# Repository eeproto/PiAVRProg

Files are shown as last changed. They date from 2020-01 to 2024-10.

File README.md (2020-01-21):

# Standalone AVR Programmer
Raspberry Pi based standalone ZIF Socket AVR Programmer

Program AVR chips with one click of a button:

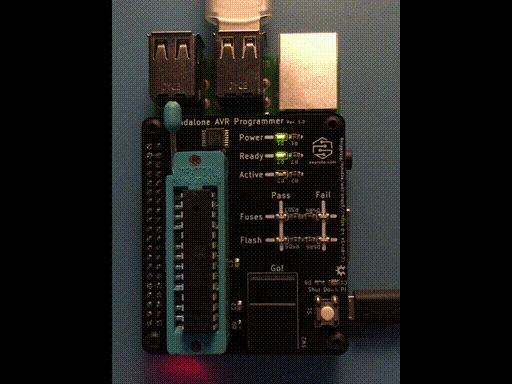
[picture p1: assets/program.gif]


Project Home Page: [https://eeproto.com/portfolio/avr-programmer/](https://eeproto.com/portfolio/avr-programmer/)

# Purpose

You designed a piece of hardware around an [AVR](https://en.wikipedia.org/wiki/AVR_microcontrollers) microcontroller, maybe the popular [ATmega328](https://www.microchip.com/wwwproducts/en/ATmega328). I love this powerful and inexpensive chip. Many projects use it, maybe because it is also the core of the even more popular [Arduino UNO](https://www.arduino.cc/en/Guide/ArduinoUno).

If you produce your new design two or three times, you flash your AVRs straight from your workstation. If you make 1,000, your distributor will gladly flash them for you. But what if you want, say, 50?

This project gives you all the parts to make a standalone, easy to use AVR programmer. It is Open Source, released under [Creative Commons Attribution-ShareAlike 4.0 International License](http://creativecommons.org/licenses/by-sa/4.0/), and it borrows from many other Open Source designs, including Sparkfun's [Pi AVR Programmer HAT](https://www.sparkfun.com/products/14747).

Hardware and software were tested with ATmega168 and ATmega328 chips. Feel free to adapt it to other AVR chips that support SPI programming.

# Make It

To make your own, get a Rasperry Pi. Any version should work, I tested it with a Pi 2 Model B v.1.1.

Make the custom PCB that connects the AVR socket, buttons, LEDs, etc. to the Pi.

Use the [KiCad](https://www.kicad-pcb.org/) project in the `hardware` folder to order your board. I got some from a low-cost PCB shop along with a stencil. It is a two-layer board with surface mount components on one side. There is a set of Gerber and drill files in the `hardware/plots` folder. The BOM in the same folder uses pretty generic components. The [octopart BOM](https://octopart.com/bom-tool/K1k6iRbx) might still be up.

Populate the surface mount components first. I use solder past, a stencil, tweezers, and a [ReflowR](http://www.reflowr.com/index.html) by [Lafras H](https://www.tindie.com/stores/LafrasH/). There are many other ways to do that, including hand soldering or reflowing with hot air like in this [EEVblog video](https://www.youtube.com/watch).

The 28 pin ZIF sockets can be a little hard to get, the major distributors might not have them in stock. Generic sockets through ama*** worked, too. Just make sure you get 28 pins in two rows with a 7.62mm / 0.3in row spacing.

If you don't feel comfortable with all of that, [email me](mailto:hello@eeproto.com), maybe I have some left over.

Add the through-hole parts. Double check you did not make any inadvertent solder bridges, then plug it in.

Support the PCB on top of your Pi with Nylon hex standoffs and secure everything with M3 screws.

Install the software by following the [Installation Guide](Installation.md).

# Prepare It

In order to program the AVR, you need two things:

1. A compiled HEX flash file.
2. The device configuration.

## 1. HEX file

Write and test your AVR firmware as usual. You can use [PlatformIO](https://platformio.org/), the [Arduino IDE](https://www.arduino.cc/en/Main/Software), a straight `avr-gcc` toolchain, or any other way. Build your project. 

Find the compiled HEX file. For Platform IO, look for a file `firmware.hex` in a folder `.pio/build/uno` underneath your project directory.

Copy this file to the root of a USB drive and name it `firmware.hex`. A standard FAT32 formatted drive works fine.

## 2. Device Configuration

Create a JSON file called `device.json` next to the HEX file on the USB drive. You can use the file from the `samples` folder as a starting point.

Adjust the AVR fuse settings to your needs. Here are a few samples:

| Fuses  | Settings |
|---|---|
| (E:FF, H:D9, L:E2) |Internal 8 MHz oscillator|
| (E:FF, H:D9, L:62) |Internal 1 MHz oscillator|
| (E:FD, H:DE, L:FF) | External 16 MHz crystal|
| (E:FD, H:DE, L:FF) | default Arduino UNO settings |

Set the chip type so avrdude knows what signature to expect. Common types:

|Type|Signature|
|---|---|
|atmega168|1e9406|
|atmega168p|1e940b|
|atmega168pb|1e9415|
|atmega328|1e9514|
|atmega328p|1e950f|
|atmega328pb|1e9516|

Check this [post](https://www.avrfreaks.net/forum/device-signatures) for a full list.

Example configuration file:
```json device.json
{
  "E": "FF",
  "H": "D9",
  "L": "E2",
  "type": "atmega328p"
}
```

# Use It

1. [Assemble](#make-it) the hardware and [install](Installation.md) the Pi firmware.
1. [Prepare](#prepare-it) the USB flash drive with your hex file and device configuration.
1. Power the Pi.
1. You should see the `Power` LED turn on.
1. The `Ready` LED is flashing until a USB drive with a valid device configuration and hex file is plugged in. Plug it in and wait for the `Ready` LED to turn solid green.
1. Insert an AVR chip that matches your device configuration into the ZIF socket and lock the socket. The index notch is at the top next to the title print.
1. Press the `Go!` button.
1. The `Active` LED turns on.
1. If the device needs updated fuse settings, the `Fuses Pass` LED should go green after a moment.
1. The `Flash Pass` LED goes green once flashing was successful.
1. If at any time a `Fail` LED starts flashing, the programmer was unsuccessful communicating with the AVR chip. Check everything is wired correctly and the AVR is secure in its place with Pin 1 at the top. Try a different AVR chip. If this problem continues to exist, try reducing the programming bitclock in the Python script. 

# How It Works

The Pi runs a small Linux OS based on PipaOS. On boot, it starts a Python script as a background system service.

This script reads the USB drive, looking for both a flash HEX file and a device configuration JSON file. 

If both are there, the script starts monitoring the big pushbutton labeled `Go!`.

When you press the button, the script runs avrdude to first check the device signature. Then, it reads the fuses. If they need to be programmed, it does that. Last, it writes the HEX file contents to the AVR flash memory.

Looking at the output of the avrdude commands, the script lights the LEDs to tell you what worked and what did not.

You can pull power from the Pi without shutting it down, because PipaOS allows the SD card to be mounted read-only.

The custom PCB mainly connects the SPI lines provided by the Pi to the AVR. A 4066 isolates the two chips when not programming, as the AVR might go into SPI master mode after releasing the RESET line. One momentary push button with a little ESD protection starts the programming, another one allows a clean shutdown of the Pi, in case you decide to run with a different OS setup.

To connect the AVR, you can use any standard socket, although a ZIF socket allows for frustration free insert and removal.

Although it looks like a HAT, technically this is not a HAT according to the [HAT Design Guide](https://github.com/raspberrypi/hats/blob/master/designguide.md). It still fits nicely on top of the Pi.

# Known Issues

For reasons I don't know, my prototype assemblies would only flash at a bitrate of around 200 kHz. A dirty breadboard assembly ran up to 2MHz. Need to figure out why that is.

# Credits

This project depends heavily on other people's great open source work, including:

- The [PipaOS](http://pipaos.mitako.eu/) Linux distribution by Albert Casals
- [avrdude](http://savannah.nongnu.org/projects/avrdude/) AVR programmer
- Kevin's [linuxspi](http://kevincuzner.com/2013/05/27/raspberry-pi-as-an-avr-programmer/) extension for avrdude
- Steve's [programmer design](https://blog.stevemarple.co.uk/2012/07/avrarduino-isp-programmer-using.html) with 74LVC244 isolating buffers
- adafruit's [linuxgpio-based design](https://learn.adafruit.com/program-an-avr-or-arduino-using-raspberry-pi-gpio-pins?view=all)
- Mark Williams shows how to operate the Pi [with the Arduino IDE](http://ozzmaker.com/program-avr-using-raspberry-pi-gpio/)
- QCPete's [writeup](https://learn.sparkfun.com/tutorials/raspberry-pi-stand-alone-programmer/all) on the design of the [Pi AVR Programmer HAT](https://www.sparkfun.com/products/14747)
- Volker Urban's [Pi/AVR summary](https://www.mikrocontroller.net/articles/Raspberry_Pi_als_Universalprogrammer) (german)
- [KiCad](https://www.kicad-pcb.org/), an exceptional and Open Source electronics design software
- Chris Gammell's [Contextual Electronics Forum](https://forum.contextualelectronics.com/) as an endless source of great knowledge.

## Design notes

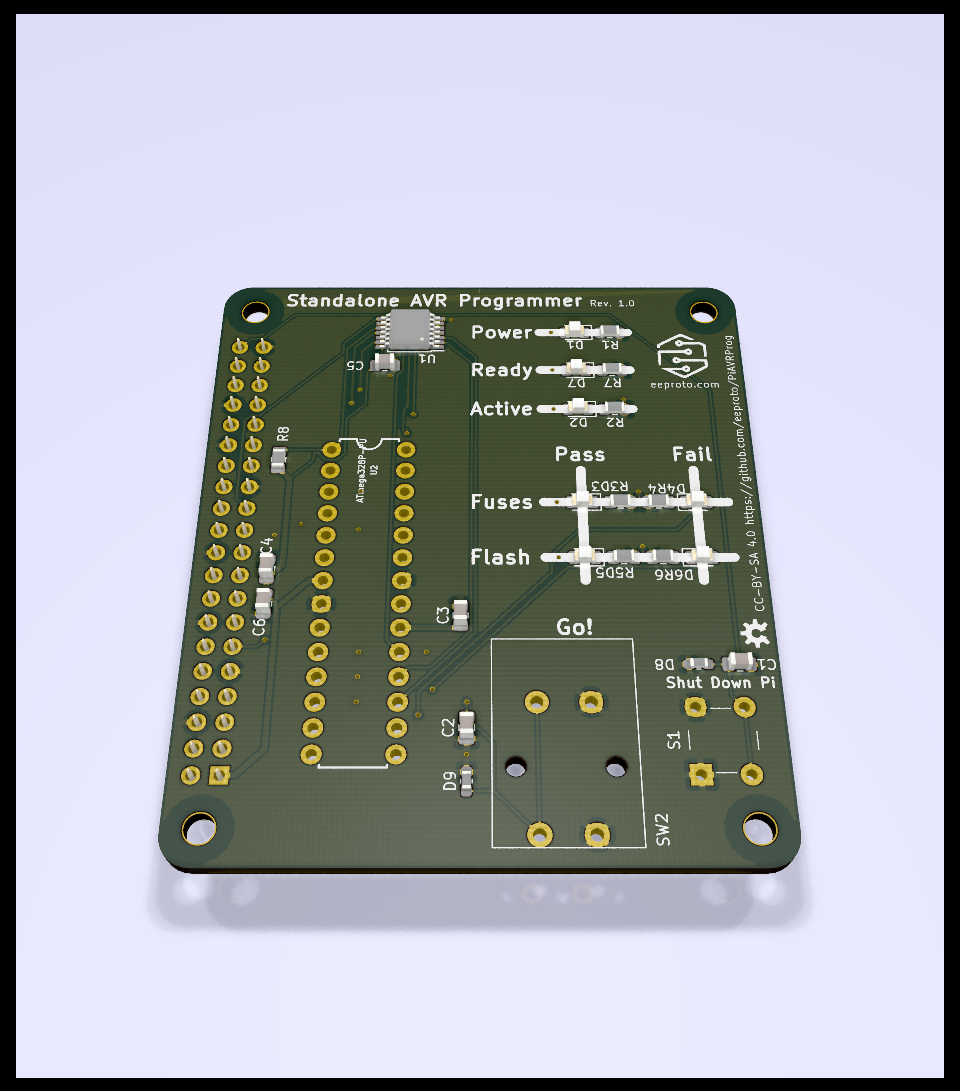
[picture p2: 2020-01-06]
hardware/PiAVRProg/plots/rendering.png

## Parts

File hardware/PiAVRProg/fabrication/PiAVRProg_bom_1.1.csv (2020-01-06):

Component | Description | Part | References | Value | Footprint | Quantity Per PCB | Datasheet | MPN | MFR | Comment | Category | Status | Family | Digi-Key_PN | DK_Datasheet_Link | DK_Detail_Page | Manufacturer
1 | Unpolarized capacitor | C | C1 C2 C3 C4 C5 | 0.1uF | C_0805_2012Metric_Pad1.15x1.40mm_HandSolder | 5 | ~ | 885012207128 | Wurth Elektronik
2 | Unpolarized capacitor | C | C6 | 10uF | C_0805_2012Metric_Pad1.15x1.40mm_HandSolder | 1 | ~ | 885012107014 | Wurth Elektronik
3 | Bidirectional transient-voltage-suppression diode | D_TVS | D8 D9 | D_TVS | R_0603_1608Metric_Pad1.05x0.95mm_HandSolder | 2 | ~ | CG0603MLE-18E | Bourns Inc.
4 | Light emitting diode | LED | D1 D3 D5 D7 | GREEN | LED_0805_2012Metric_Pad1.15x1.40mm_HandSolder | 4 | ~ | LTST-S220GKT LTST-S220EKT | Lite-On | Power Fuse Pass Flash Pass Ready
5 | Light emitting diode | LED | D4 D6 | RED | LED_0805_2012Metric_Pad1.15x1.40mm_HandSolder | 2 | ~ | LTST-S220EKT | Lite-On | Fuse Fail Flash Fail
6 | Light emitting diode | LED | D2 | YELLOW | LED_0805_2012Metric_Pad1.15x1.40mm_HandSolder | 1 | ~ | LTST-S220KSKT | Lite-On | Programming
7 |  | OX40HAT-raspberrypi_hat | J1 | 40HAT | PinSocket_2x20_P2.54mm_Vertical | 1 |  | SSW-120-01-T-D | Samtec Inc.
8 | Resistor | R | R1 R2 R3 R4 R5 R6 R7 | 100 | R_0805_2012Metric_Pad1.15x1.40mm_HandSolder | 7 | ~ | RC0805FR-07100RL | Yageo
9 | Resistor | R | R8 | 10k | R_0805_2012Metric_Pad1.15x1.40mm_HandSolder | 1 | ~ | RC0805FR-0710KL | Yageo
10 | SWITCH TACTILE SPST-NO 0.05A 24V | B3F-1000 | S1 | B3F-1000 | Switch_Tactile_THT_B3F-1xxx | 1 | https://omronfs.omron.com/en_US/ecb/products/pdf/en-b3f.pdf | B3F-1000 | Omron Electronics Inc-EMC Div | Shut Down | Switches | Active | Tactile Switches | SW400-ND | https://omronfs.omron.com/en_US/ecb/products/pdf/en-b3f.pdf | /product-detail/en/omron-electronics-inc-emc-div/B3F-1000/SW400-ND/33150 | Omron Electronics Inc-EMC Div
11 | Single Pole Single Throw (SPST) switch | SW_SPST | SW2 | MOM | OmronB3J1100 | 1 | ~ | B3J-1100 | Omron Electronics Inc-EMC Div | Go!
12 | Quad Analog Switches | 4066 | U1 | 4066 | TSSOP-14_4.4x5mm_P0.65mm | 1 | http://www.ti.com/lit/ds/symlink/cd4066b.pdf | 74LVC4066PW,118 | Nexperia USA Inc.
13 | 20MHz, 32kB Flash, 2kB SRAM, 1kB EEPROM, DIP-28 | ATmega328P-PU | U2 | ATmega328P-PU | DIL28-3-ZIF_SOCKET | 1 | http://ww1.microchip.com/downloads/en/DeviceDoc/ATmega328_P%20AVR%20MCU%20with%20picoPower%20Technology%20Data%20Sheet%2040001984A.pdf | 28-3551-10 | Aries Electronics
Component Groups: | 13
Component Count: | 28
Fitted Components: | 28
Number of PCBs: | 1
Total components: | 28
Schematic Version: | 1.1
Schematic Date: | 2020-01-02
PCB Variant: | [u'default']
BoM Date: | Mon 06 Jan 2020 12:44:06 PM EST
Schematic Source: | /home/christian/archiv/clients/open source/piavr/PiAVRProg/hardware/PiAVRProg/PiAVRProg.sch
KiCad Version: | Eeschema 5.0.2-bee76a0~70~ubuntu18.04.1

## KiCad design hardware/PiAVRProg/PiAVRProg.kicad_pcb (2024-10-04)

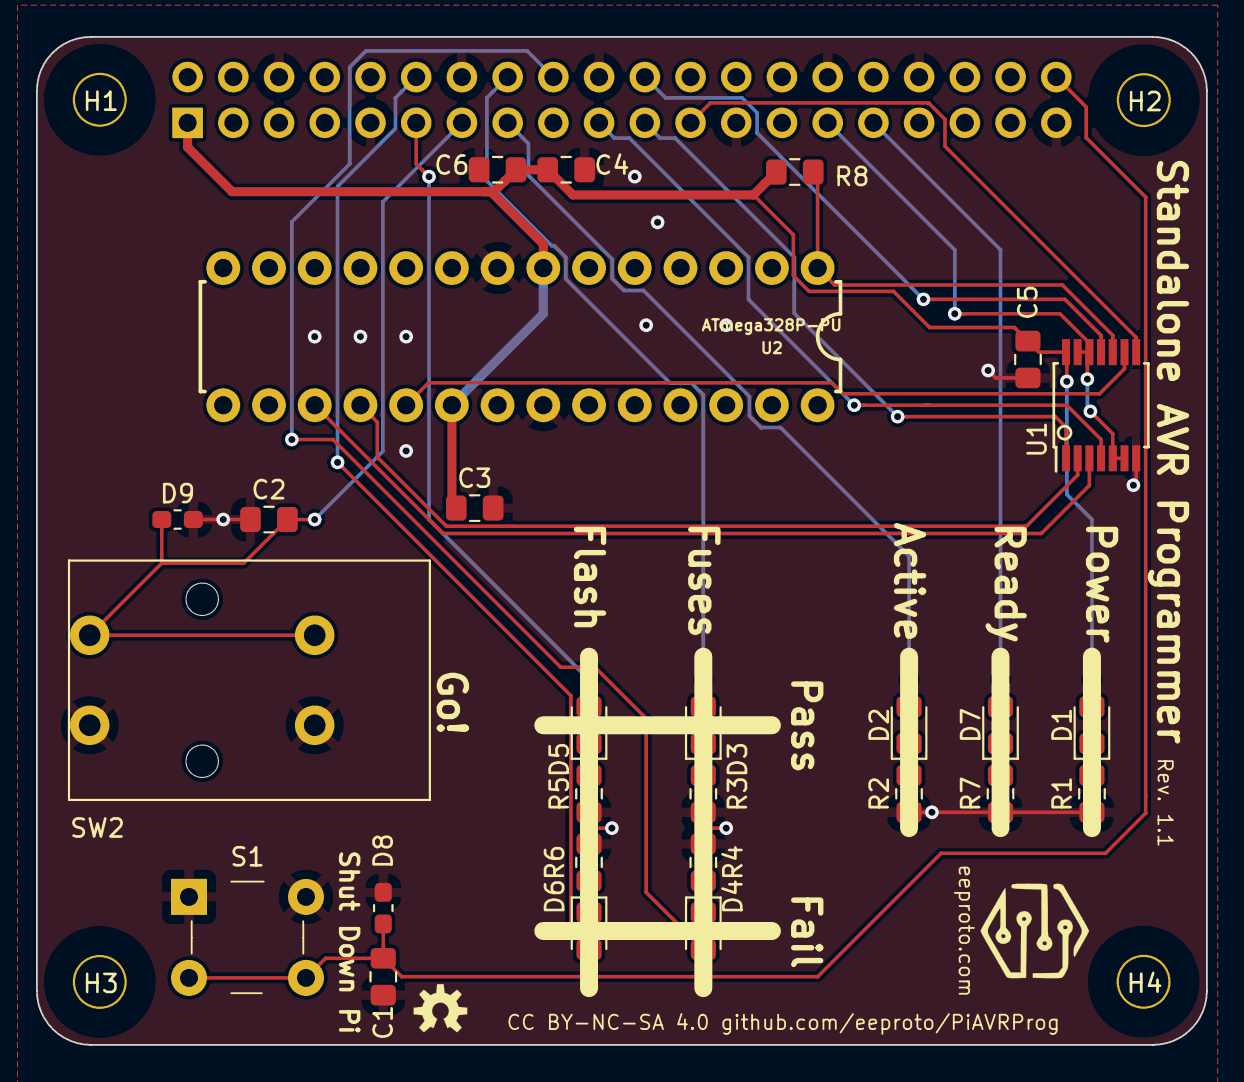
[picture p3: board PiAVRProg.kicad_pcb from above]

Board: 2 copper layers, 65.0 x 56.0 mm, 32 parts (1 on the bottom side), 26 nets.

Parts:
C1, C2, C3, C4, C5: 0.1uF; C_0805_2012Metric_Pad1.15x1.40mm_HandSolder
C6: 10uF; C_0805_2012Metric_Pad1.15x1.40mm_HandSolder
D1, D3, D5, D7: GREEN; LED_0805_2012Metric_Pad1.15x1.40mm_HandSolder
D2: YELLOW; LED_0805_2012Metric_Pad1.15x1.40mm_HandSolder
D4, D6: RED; LED_0805_2012Metric_Pad1.15x1.40mm_HandSolder
D8, D9: D_TVS; R_0603_1608Metric_Pad1.05x0.95mm_HandSolder
H1, H2, H3, H4: 3mm_Mounting_Hole; NPTH_3mm_ID
J1: 40HAT; PinSocket_2x20_P2.54mm_Vertical
R1, R2, R3, R4, R5, R6, R7: 1k; R_0805_2012Metric_Pad1.15x1.40mm_HandSolder
R8: 10k; R_0805_2012Metric_Pad1.15x1.40mm_HandSolder
S1: B3F-1000; Switch_Tactile_THT_B3F-1xxx
SW2: MOM; OmronB3J1100
U1: 4066; TSSOP-14_4.4x5mm_P0.65mm
U2: ATmega328P-PU; DIL28-3-ZIF_SOCKET

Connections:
+3V3: C3.1, C4.1, C5.1, C6.1, D1.2, J1.1, R8.1, U1.14, U2.7, U2.20
/AVR_CLK: U1.9, U2.19
/AVR_MISO: U1.2, U2.18
/AVR_MOSI: U1.3, U2.17
/AVR_RESET: R8.2, U1.10, U2.1
/FLASH_FAIL: D6.2, J1.12
/FLASH_PASS: D5.2, J1.11
/FUSE_FAIL: D4.2, J1.18
/FUSE_PASS: D3.2, J1.16
/PI_CLK: J1.23, U1.8
/PI_GO: C2.2, D9.1, J1.13, SW2.1
/PI_MISO: J1.21, U1.1
/PI_MOSI: J1.19, U1.4
/PI_RESET: J1.22, U1.11
/PI_SHUTDOWN: C1.2, D8.1, J1.40, S1.3, S1.4
/PROGRAMMING: D2.2, J1.15
/READY: D7.2, J1.31
/SPI_SWITCH: J1.29, U1.5, U1.6, U1.12, U1.13
GND: C1.1, C2.1, C3.2, C4.2, C5.2, C6.2, D8.2, D9.2, J1.6, J1.9, J1.14, J1.20, J1.25, J1.30, J1.34, J1.39, R1.1, R2.1, R3.1, R4.1, R5.1, R6.1, R7.1, S1.1, S1.2, SW2.2, U1.7, U2.8, U2.22
unnamed: D1.1, R1.2
unnamed: D2.1, R2.2
unnamed: D3.1, R3.2
unnamed: D4.1, R4.2
unnamed: D5.1, R5.2
unnamed: D6.1, R6.2
unnamed: D7.1, R7.2

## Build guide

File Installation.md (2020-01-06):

# Software Installation

The Software for this Programmer is built on top a Linux distribution. I chose [PipaOS](http://pipaos.mitako.eu/) by Albert Casals because it is fast, slim, can be installed as a read-only SD-card image, and it is generally great work. The read-only image helps extending the life of SD cards a lot.

If you want a ready-to-go image instead of going through the installation, [let me know](mailto:hello@eeproto.com) as I plan to upload one.

## 1. Install The OS

Grab a fresh SD card, min. 2 GB, and download your choice of PipaOS image. I used [pipaos-stretch-6.0.img.gz](http://pipaos.mitako.eu/download/pipaos-stretch-6.0.img.gz). Use an SD-card adapter to write the image. There are plenty of tools out there, like the [balena Etcher](https://www.balena.io/etcher/). Or use `dd`. Or `dc3dd`, which works like `dd` but is a little more talkative. Writing through the `/dev/disk/by-id/` nodes instead of `/dev/sdx` helps you to flash the SD card and not accidentally your hard disk.

```bash
wget http://pipaos.mitako.eu/download/pipaos-stretch-6.0.img.gz
sudo umount /dev/disk/by-id/usb-SanDisk_SDDR-B531_012345-0*
zcat ~/Downloads/pipaos-stretch-6.0.img.gz | sudo dc3dd verb=on of=/dev/disk/by-id/usb-SanDisk_SDDR-B531_012345-0\:0
```

## 2. Configure The OS

Get access to your freshly installed OS. 

Plug the SD card into your Pi, hook it up to your Ethernet, boot it up, and SSH into it. The default credentials are user `sysop` and password `posys`. Your router might be smart enough to pick up the default hostname `pipaos`. If not, use `nmap` to find a MAC address that looks like a Pi:

```bash
# with hostname resolution
ssh sysop@pipaos

# without
sudo nmap -sP 192.168.1.1-254
# look for something like this:
#   Nmap scan report for 192.168.1.29
#   Host is up (-0.099s latency).
#   MAC Address: B8:27:xx:xx:xx:xx (Raspberry Pi Foundation)
ssh sysop@192.168.1.29
```
Make your basic OS settings, something like this:
```bash
# always change the password first
passwd

# update and install a few useful tools including avrdude
sudo apt update
sudo apt install -y vim python3-virtualenv virtualenv screen git avrdude ntpdate
sudo apt upgrade

# choose and set your hostname
export HOSTNAME=piavr
sudo sed -i -e "s/pipaos/$HOSTNAME/" /etc/hosts
sudo sed -i -e "s/pipaos/$HOSTNAME/" /etc/hostname

# set your timezone and set the clock
sudo dpkg-reconfigure tzdata
sudo service ntp stop
sudo ntpdate pool.ntp.org

# disable a few services for faster startup
#  you can skip this if you don't know what these are
sudo systemctl disable avahi-daemon
sudo systemctl disable triggerhappy
sudo systemctl disable ntp
sudo systemctl disable wpa_supplicant
sudo systemctl disable apt-daily
sudo systemctl disable apt-daily-upgrade
sudo systemctl disable pipaos-bootlogo
sudo apt remove alsa-utils
```

Make sure [SPI is enabled](https://www.raspberrypi.org/documentation/hardware/raspberrypi/spi/README.md) by checking:

```bash
lsmod | grep spi
grep spi /boot/config.txt
```
 
`lsmod` should should report a module `spidev` loaded.

This line has to be in `/boot/config.txt` without a comment `#` sign in front:

```ini
dtparam=spi=on
```

## 3. Auto Mount USB Drive 

The AVR Hex file and device configuration will be supplied on a removable USB drive. We want to plug it into the Pi at any time without worrying about mounting it manually.

This modifies your `/etc/fstab` do to just that:

```bash
sudo mkdir /media/usb
sudo chattr +i /media/usb
echo "/dev/sda1  /media/usb  vfat  defaults,sync,nofail,noexec,nosuid,noatime,nodev,user  0 0" | sudo tee -a /etc/fstab
```

## 4. avrdude

We will use [avrdude](http://savannah.nongnu.org/projects/avrdude/) to actually program the AVR. Make sure we got the right version from the repo. You want at version 6.1 or newer with linux SPI support:

```bash
avrdude
# check to see "version 6.1" or newer

avrdude -c ?type 2> >(grep linux)
# look for a line starting with "linuxspi"
```

## 5. Python Scripts

For programming standalone, the Pi will run a background service that works with the buttons, LEDs, and avrdude. Install it from github and enable it:

```bash
# choose where you would like to install this
cd /var/lib/
sudo mkdir piavr
sudo chown sysop piavr
cd piavr

# wrap it into a virtual environment
virtualenv --python=/usr/bin/python3 .
source /var/lib/piavr/bin/activate
git clone https://github.com/eeproto/PiAVRProg
pip install -r PiAVRProg/software/scripts/requirements.txt

# install as a system service on boot
sudo ln -snf /var/lib/piavr/PiAVRProg/software/etc_systemd_system/avrprogrammer.service \
 /etc/systemd/system
sudo systemctl enable avrprogrammer.service
```

## Finish

Finally, make the root filesystem read-only:

```bash
sudo pipaos-lockfs lock persistent
```

If you need to make changes in the future, boot, log in, and temporarily remount as read-write:
```bash
sudo pipaos-lockfs unlock
# do stuff ..
sudo pipaos-lockfs lock
sudo reboot
```
PipaOS is great, right?

You could also do all that by mounting the SD card on your computer like this and do some clever chrooting:

```bash
sudo mount /dev/disk/by-id/usb-SanDisk_SDDR-B531_012345-0\:0-part1 /media/boot
sudo mount /dev/disk/by-id/usb-SanDisk_SDDR-B531_012345-0\:0-part2 /media/root
# ...
```

## Troubleshoot

Here are a few things you can try in case things don't work as expected. Log in to the Pi and do this on the commandline.

Plug in a fresh AVR chip and see if avrdude can find it: 
```bash
sudo avrdude -c linuxspi -v -p atmega328p -P /dev/spidev0.0
```

Try reading a few things from the chip:
```bash
# read signature at a low baud rate
sudo avrdude -c linuxspi -v -p atmega328p -b19200 -B10 -P /dev/spidev0.0
 
# read flash to binary file at 2MHz SPI clock
sudo avrdude -c linuxspi -v -p atmega328p -P /dev/spidev0.0 -v \
 -b 2000000 \
 -U flash:r:/tmp/flash.bin:r
```

Try manually writing:
```bash
# write fuses, -D no auto erase, 19200 SPI clock rate
sudo avrdude -c linuxspi -v -p atmega328p -P /dev/spidev0.0 -v \
 -b 19200 -B10 \
 -U efuse:w:0xFF:m -U hfuse:w:0xD9:m -U lfuse:w:0xE2:m
 
# write flash, no auto erase, -e chip erase, 2 MHz SPI clock
sudo avrdude -c linuxspi -v -p atmega328p -P /dev/spidev0.0 -v \
 -b 2000000 \
 -U flash:w:/tmp/firmware.hex:i
```

Try different bit clock rates and baud rates. Check the [online docs](https://www.nongnu.org/avrdude/user-manual/avrdude.html) for details. Modify the Python scripts accordingly.

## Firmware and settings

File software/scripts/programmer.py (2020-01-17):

#!/usr/bin/env python
# -*- coding: utf-8 -*-

"""
This file is part of the PiAVRProg project
 https://github.com/eeproto/PiAVRProg

This work is licensed under a Creative Commons Attribution-ShareAlike 4.0
 International License http://creativecommons.org/licenses/by-sa/4.0/

Copyright (c) 2019 EE Proto LLC https://www.eeproto.com

Author: christian@eeproto.com
"""

import RPi.GPIO as GPIO
import time
import json
import os
import logging
import traceback
import signal
import sys

import led
import button
import avrdude

DEVICE_FILE_PATH = '/media/usb/device.json'
FLASH_FILE_PATH = '/media/usb/firmware.hex'
DEVICE_KEYS = ['H', 'L', 'E', 'type']
SPI_DEVICE = '/dev/spidev0.0'
PROGRAMMER = 'linuxspi'
BAUDRATE_SLOW = '19200'
BITRATE_SLOW = '10'
BAUDRATE_FAST = '200000'
BITCLOCK_FAST = '1'
LOG_LEVEL = logging.INFO
VERSION = '0.2'


class PiProgrammer(object):

    def __init__(self):
        self.init_gpio()
        self.leds = {}
        self.led_ready = led.LED(6)
        self.leds['programming'] = led.LED(22)
        self.leds['flash_pass'] = led.LED(17)
        self.leds['flash_fail'] = led.LED(18)
        self.leds['fuse_pass'] = led.LED(23)
        self.leds['fuse_fail'] = led.LED(24)
        self.buffer_switch = led.LED(5)
        self.go_button = button.Button(27, self.button_pressed)
        self.clear_leds()
        self._alive = True

    def init_gpio(self):
        GPIO.setwarnings(False)
        GPIO.setmode(GPIO.BCM)

    def led_cycle(self, *args):
        l = list(self.leds.keys())
        l.sort()
        self.leds[l[self.x]].off()
        self.x = (self.x + 1) % len(self.leds)
        self.leds[l[self.x]].on()

    def clear_leds(self):
        for l in self.leds.values():
            l.off()
        self.led_ready.off()

    def load_firmware(self):
        device = {}
        try:
            logging.debug('reading device configuration from %s', DEVICE_FILE_PATH)
            with open(DEVICE_FILE_PATH, 'r') as f:
                device = json.load(f)
            device_ok = (len(set(device.keys()) & set(DEVICE_KEYS)) == len(DEVICE_KEYS))
            logging.debug('found %s keys in device file %s', len(DEVICE_KEYS), DEVICE_FILE_PATH)
        except Exception as ex:
            device_ok = False
            logging.error('error loading device file: %s', ex)
        try:
            logging.debug('opening flash file %s', FLASH_FILE_PATH)
            flash_size = os.path.getsize(FLASH_FILE_PATH)
            logging.debug('found %s byte flash file %s', flash_size, FLASH_FILE_PATH)
            flash_ok = (flash_size > 0)
        except Exception as ex:
            flash_ok = False
            logging.error('error loading flash file: %s', ex)
        return device, device_ok, flash_ok

    def button_pressed(self, *args):
        self.clear_leds()
        if self._ready_to_go:
            try:
                logging.info('begin programming')
                self.leds['programming'].on()
                self.buffer_switch.on()
                self.run_programming()
            except avrdude.AvrDeviceNotRespondingError as ex:
                logging.error('device not ready %s %s', type(ex), ex.args)
                logging.debug(traceback.format_exc())
                self.leds['fuse_fail'].blink(500, 500)
            except avrdude.SignatureReadError as ex:
                logging.error('can not read sig %s %s', type(ex), ex.args)
                logging.debug(traceback.format_exc())
                self.leds['flash_fail'].blink(500, 500)
            except avrdude.SignatureDoesNotMatchError as ex:
                logging.error('signature mismatch %s %s', type(ex), ex.args)
                logging.debug(traceback.format_exc())
                self.leds['fuse_pass'].blink(500, 500)
            except Exception as ex:
                logging.error('programming error %s %s', type(ex), ex.args)
                logging.debug(traceback.format_exc())
            finally:
                self.buffer_switch.off()
                self.leds['programming'].off()

    def run_programming(self):
        dude = avrdude.AvrDude(
            self.device['type'],
            SPI_DEVICE, PROGRAMMER, BAUDRATE_SLOW, BITRATE_SLOW, BAUDRATE_FAST, BITCLOCK_FAST)
        read_signature = dude.verify_signature_and_fuses()
        logging.info('device signature verified as %s', read_signature)
        time.sleep(0.1)
        read_fuses = dude.read_fuses()
        fuses_same = (
                self.device['E'] == read_fuses['E'] and
                self.device['H'] == read_fuses['H'] and
                self.device['L'] == read_fuses['L']
        )
        logging.info('device fuses read %s, same as device settings? %s', read_fuses, fuses_same)
        if not fuses_same:
            time.sleep(0.1)
            fuses_ok = dude.write_fuses(
                E=self.device['E'],
                H=self.device['H'],
                L=self.device['L'],
            )
            logging.info('fuse write done')
            if fuses_ok:
                self.leds['fuse_pass'].on()
                self.leds['fuse_fail'].off()
            else:
                self.leds['fuse_pass'].off()
                self.leds['fuse_fail'].on()
        time.sleep(0.1)
        flash_ok = dude.write_flash(FLASH_FILE_PATH)
        logging.info('flash write result %s', flash_ok)
        if flash_ok:
            self.leds['flash_pass'].on()
            self.leds['flash_fail'].off()
        else:
            self.leds['flash_pass'].off()
            self.leds['flash_fail'].on()

    def run(self):
        while self._alive:
            self.device, device_file_ok, flash_file_ok = self.load_firmware()
            self._ready_to_go = device_file_ok and flash_file_ok
            if self._ready_to_go:
                self.led_ready.on()
            else:
                self.led_ready.blink(500, 500)
            time.sleep(2)
        logging.info('shut down')

    def shutdown(self):
        self._alive = False
        self.clear_leds()
        sys.exit(0)




def signal_received_handler(signum, frame):
    logging.info("signal %s received in frame %s", signum, frame)
    if signum in (signal.SIGINT, signal.SIGTERM):
        global prog
        prog.shutdown()


def main():
    signal.signal(signal.SIGINT, signal_received_handler)
    signal.signal(signal.SIGTERM, signal_received_handler)
    signal.signal(signal.SIGHUP, signal_received_handler)
    signal.signal(signal.SIGTSTP, signal_received_handler)
    logging.basicConfig(level=LOG_LEVEL)
    logging.info('PiAVR programmer version %s', VERSION)
    global prog
    prog = PiProgrammer()
    prog.run()


if __name__ == '__main__':
    main()

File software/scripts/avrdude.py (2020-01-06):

# -*- coding: utf-8 -*-

"""
This file is part of the PiAVRProg project
 https://github.com/eeproto/PiAVRProg

This work is licensed under a Creative Commons Attribution-ShareAlike 4.0
 International License http://creativecommons.org/licenses/by-sa/4.0/

Copyright (c) 2019 EE Proto LLC https://www.eeproto.com

Author: christian@eeproto.com
"""

import subprocess
import logging
import re
import traceback


class GpioAccessDeniedError(Exception):
    pass


class AvrDeviceNotRespondingError(Exception):
    pass


class SignatureReadError(Exception):
    pass


class SignatureDoesNotMatchError(Exception):
    pass


class FuseFormatError(Exception):
    pass


class FuseWriteError(Exception):
    pass


class FuseReadError(Exception):
    pass


class FlashWriteError(Exception):
    pass


DEVICE_SIGNATURES = {
    'm168': '1e9406',
    'atmega168': '1e9406',
    'm168p': '1e940b',
    'atmega168p': '1e940b',
    'm168pb': '1e9415',
    'atmega168pb': '1e9415',
    'm328': '1e9514',
    'atmega328': '1e9514',
    'm328p': '1e950f',
    'atmega328p': '1e950f',
    'm328pb': '1e9516',
    'atmega328pb': '1e9516',
}

HEX_BYTE_MATCH = re.compile(r'^[0-9A-Fa-f]{2}$')


class AvrDude(object):

    def __init__(self, chip_type, programming_device, programmer,
                 baudrate_slow, bitclock_slow,
                 baudrate_fast, bitclock_fast):
        self.chip_type = chip_type
        self.programming_device = programming_device
        self.programmer = programmer
        self.baudrate_slow = baudrate_slow
        self.bitclock_slow = bitclock_slow
        self.baudrate_fast = baudrate_fast
        self.bitclock_fast = bitclock_fast

    def verify_signature_and_fuses(self):
        logging.info('reading device signature to verify chip type')
        result = self._command(
            baudrate=self.baudrate_slow,
            bitclock=self.bitclock_slow,
        )
        try:
            expected = DEVICE_SIGNATURES[self.chip_type.lower()]
            # https://pythex.org/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
            signature_pattern = re.compile(r'avrdude: Device signature = 0x([0-9A-Fa-f]+)')
            signature = signature_pattern.search(result).group(1)
        except Exception as ex:
            logging.debug(traceback.format_exc())
            raise SignatureReadError('unable to read signature', ex)
        if not signature == expected:
            raise SignatureDoesNotMatchError('signature does not match, read {}, expected {}'.format(
                signature, expected
            ))
        return signature

    def read_fuses(self):
        logging.info('reading fuses')
        result = self._command(
            baudrate=self.baudrate_slow,
            bitclock=self.bitclock_slow,
            read_fuses=True,
        )
        try:
            fuses = {}
            fuse_pattern = re.compile(r'01000000([0-9A-Fa-f]{2}).*\n:00000001FF')
            match = fuse_pattern.findall(result)
            fuses['E'] = match[0]
            fuses['H'] = match[1]
            fuses['L'] = match[2]
            logging.debug('read fuses %s', fuses)
        except Exception as ex:
            logging.debug(traceback.format_exc())
            raise FuseReadError('unable to read fuses', ex)
        return fuses

    def write_fuses(self, E=None, H=None, L=None):
        logging.info('writing fuses E=%s H=%s L=%s', E, H, L)
        result = self._command(
            baudrate=self.baudrate_slow,
            bitclock=self.bitclock_slow,
            write_E_fuse=E,
            write_H_fuse=H,
            write_L_fuse=L,
        )
        errors = []
        if E is not None:
            if not 'efuse verified' in result:
                errors.append('E fuse write error')
            else:
                logging.debug('E fuse write ok')
        if H is not None:
            if not 'hfuse verified' in result:
                errors.append('H fuse write error')
            else:
                logging.debug('H fuse write ok')
        if L is not None:
            if not 'lfuse verified' in result:
                errors.append('L fuse write error')
            else:
                logging.debug('L fuse write ok')
        if len(errors) > 0:
            raise FuseWriteError(', '.join(errors))
        else:
            return True

    def write_flash(self, flash_file):
        logging.info('writing flash file %s', flash_file)
        result = self._command(
            baudrate=self.baudrate_fast,
            bitclock=self.bitclock_fast,
            chip_erase=True,
            write_flash_file=flash_file,
        )
        try:
            flash_write_match = re.search(r'(\d+) bytes of flash verified', result)
            bytes_flashed = int(flash_write_match.group(1))
            logging.info('wrote %s bytes to flash', bytes_flashed)
            return True
        except Exception as ex:
            logging.debug(traceback.format_exc())
            raise FlashWriteError('unable to write flash', ex)
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

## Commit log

2020-01-06 initial github commit
    [PiAVRProg.kicad_pcb, PiAVRProg.sch, PiAVRProg_bom_1.1.csv]
2020-01-21 pin 1 indicator
    [PiAVRProg.kicad_pcb]
2024-10-04 kicad 8
    [PiAVRProg.kicad_pcb, PiAVRProg.kicad_sch, PiAVRProg.sch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]

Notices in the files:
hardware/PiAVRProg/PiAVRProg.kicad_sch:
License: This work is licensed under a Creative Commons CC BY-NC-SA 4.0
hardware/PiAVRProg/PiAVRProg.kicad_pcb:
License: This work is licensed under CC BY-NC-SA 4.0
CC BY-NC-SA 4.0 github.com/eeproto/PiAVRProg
